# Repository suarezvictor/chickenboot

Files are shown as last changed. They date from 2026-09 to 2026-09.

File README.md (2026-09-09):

# ChickenBoot

The unbrickable and versatile embeddable boot loader  

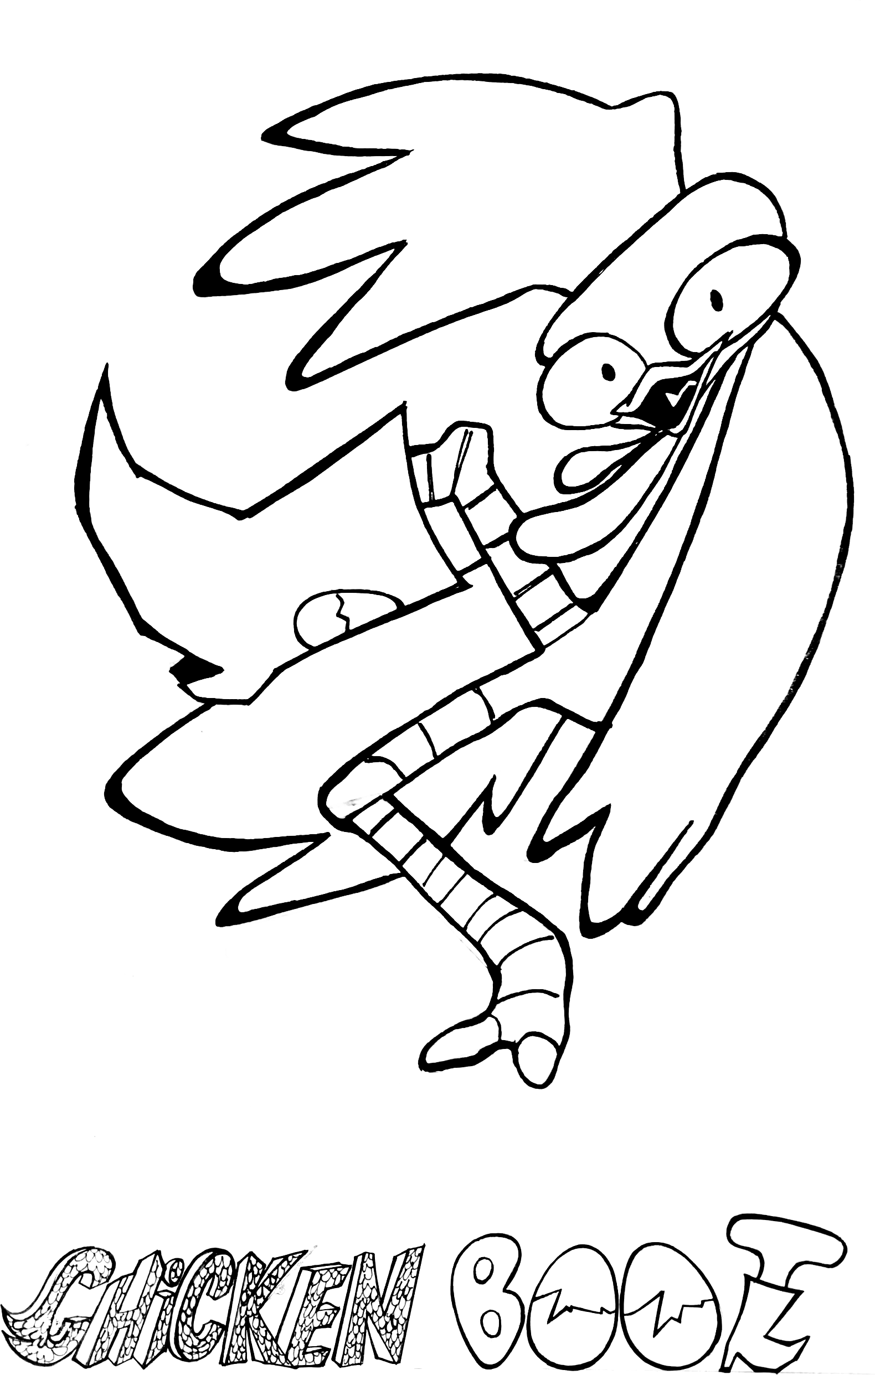
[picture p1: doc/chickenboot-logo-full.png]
  

# Building

To build the firmware:  
```
export PICO_SDK_PATH=$HOME/pico/pico-sdk

cd firmware
cmake -S . -B build -DPICO_BOARD=pico
make -C build -j
```

Then copy the build/main.uf2 file to the virtual drive (created by holding the BOOT button, the usual label for the drive is RPI-RP2)
# PCB design files

There are two board designs: one based on a MCU from WCH, the other based on a Raspberry Pi Pico.  

for details, read [Design document](DESIGN.md)

## View the boards online:  
The interactive viewer allows to explore the design in full without the need of installing any tools

- [RPI based design](https://kicanvas.org/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)

- [WCH based design](https://kicanvas.org/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)

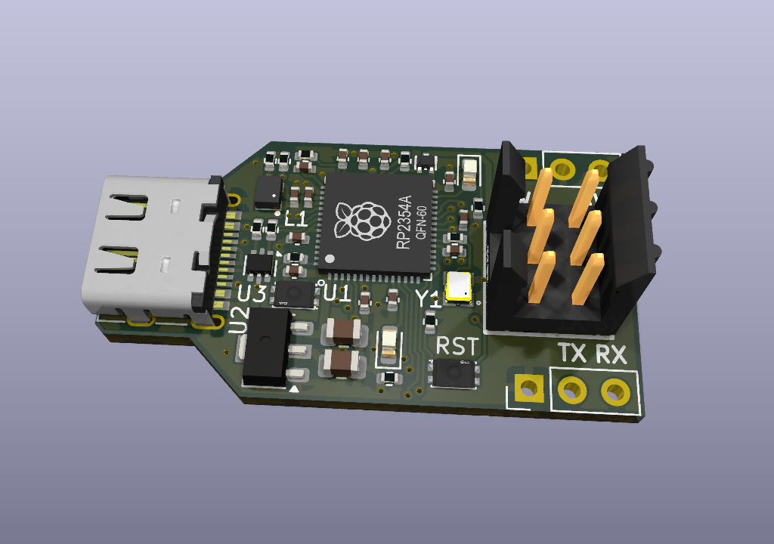
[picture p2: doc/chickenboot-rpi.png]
  
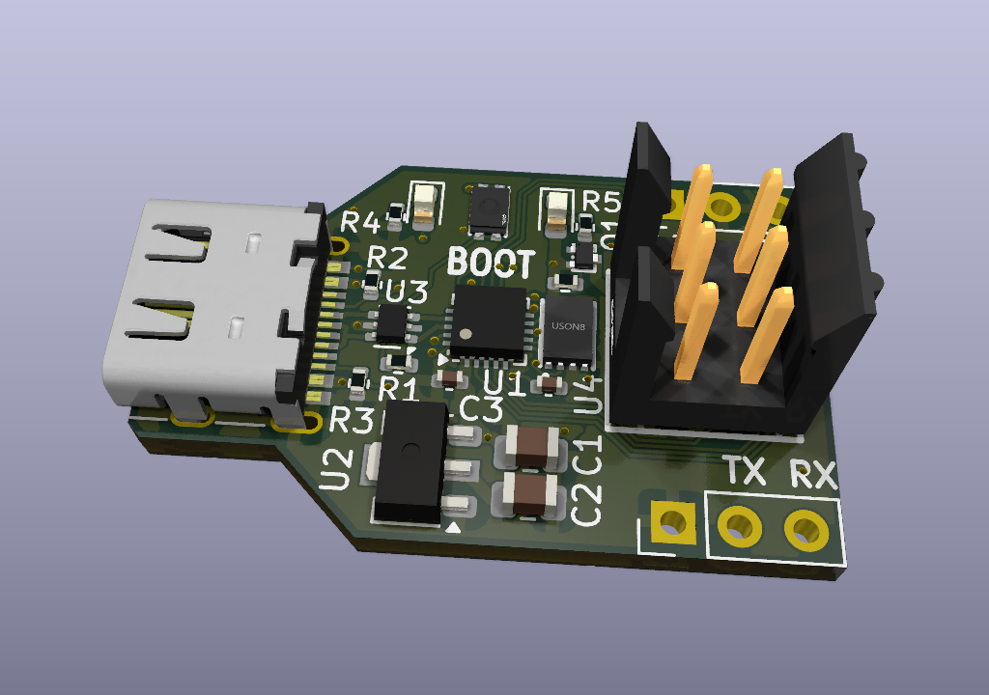
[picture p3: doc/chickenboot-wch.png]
  

# Licensing
Hardware design files are licensed under the [CERN-OHL-S-2.0](https://opensource.org/license/CERN-OHL-S-2.0) unless otherwise stated.  
Source code is licensed under the [AGPL-3.0](https://opensource.org/license/agpl-3-0) unless otherwise stated.  
  
# Funding
This project is supported by [The Open Source Firmware Foundation](https://www.osfw.foundation/)

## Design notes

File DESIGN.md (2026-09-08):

#Design criteria
## Objective
The current objective of the project aims to provide a practically negligible-cost, self-recovering, autonomous FPGA/MCU programming subsystem that can be embedded into embedded products.

# MCU selection

## Hard requirements
* Unbrickable: the MCU includes a bootloader in ROM
* No need of external adapters: the ROM bootloader suppoprts USB
* Small size: to prevent adding "real estate" requirements in PCB. Targew is 7x7mm max.
* Very low cost: if cost were high, it would justify an external programmer. Target is $2 max.

## Desirable features
* Large internal flash: So it can replace the flash required by FPGAs or complex SoC
* No radio: the radio of some MCUs adds a compliance burden for marketable designs.
* No BGA package: to simplify PCB and reduce cost

After evaluating those requirements, the *RP2354A* MCU appears to be a unicorn device, since the only capable of satisfying all of the above: 7x7mm package and 2 MB flash, at just $1.2.
Notable alternatives in a small package are ESP32 and Bouffalo Labs MCUs, being small, cheap and with considerable flash. but they have the radio issue, or Artery AT32F435CMU7, but about $3 and less mature ecosystem.
Others from WCH like CH32V203F8U6 and CH32X035F8U6 comes in 3x3mm package and at < $0.5 cost, but it lacks a large internal flash.

There is an issue regarding using just 2 MB of flash since some FPGAs expect up to 64MB for bistestream storage. But it is solvable by usign an external flash with a RP2040/RP2350 MCU, or by compression (tested bitstreams are about 4X compressible with lightweight algorithms like LZ4 which is truly fast for streaming decompression).

Note that the RP2350 has a internal 1.1V DC-DC requiring a 2x1.6mm inductor (not needed by the RP2040 LDO) but this can be skipped since the core voltage of the MCU matches the core voltage of FPGAs and the MCU is known for its flexibility of voltage and frequency of operation, so the same supply can be used saving PCB area.

# WCH board option

A board based on the CH32X035F8U6 MCU was also designed paired with an external ISSI IS25WP016D-JULE-TR 16mbit flash (2x3mm), considering a WINBOND W25Q16JVUXIQ alternative but more expensive.

Combined area usage gets effectively 6.5x3mm, and price stays below $1, but it is expected that the firmware for this platform will be more complex (TinyUSB support is not as good) and also slower: its 48Mhz clock is significantly slower than the 150Mhz (overclockable) RP2354 which has a full featured PIO. The CH32X035 provides a PIOC but with restrictions on pin usage (not possible in the 20 pin version) and DMA clobbers unintended I/O pins.

# Firmware
## Desirable features
* Device agnostic: it would add much complexity if each device needs its custom algorithm 
* Firmware simplicity: restricting the capability of this firmware to upload the bitstream (or program) just to RAM eliminates the unpredictable timings of flash access. Lack of flash programming is not an issue since the selected MCU will store the bitstream of firmware to be run, so the device doesn't need to fetch it from a local flash.
* Ease of use at production by non-technical users: UF2 uploader imposeses *no drivers or tools installation on the host (PC), since the programmer shows as a "thumb" driver where the programming file can be copied.

Considering this, the format to store the programming data was XSVF: most FPGA tools generate SVF (ASCII format), but this is convertible to XSVF (binary format) by tools like OpenOCD's svf2xsvf. The firmware on the MCU need only to convert the XSVF commands to JTAG signals, and since the XSVF is generated once at the host, this makes it device agnostic (the host knows the nuances of each device to be programmed). Note that SVF files generally lacks polling commands to check "busy" bits, but those are really needed for programming flash devices, SRAM target can use worst-case timings since they're really small (a few clocks). In any case, XSVF supports wait loops that can be exploited for programming more complex devices.

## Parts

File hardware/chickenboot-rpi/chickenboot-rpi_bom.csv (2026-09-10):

Comment | Designator | Footprint | LCSC Part Number | MPN | MFG
100n | C18,C16,C14,C11,C8,C15,C13,C12,C17 | 0402 | C100072 | CL05A104KA5NNNC | Samsung Electro-Mechanics
1k | R1,R6 | 0402 | C105637 | RC0402JR-071KL | YAGEO
69168-106HLF | CN1 | CONN-TH_6P-P2.54_69168-X06 | C5410110 | 69168-106HLF
3.3u | L1 | L_pol_2016 | C42411119 | AOTA-B201610S3R3-101-T
10uF 10V | C1,C2 | 0805 | C32635
27 | R5,R8,R7,R9 | 0402 | C25100 | 0402WGF270JTCE | UNI-ROYAL(Uniroyal Elec)
RP2350_60QFN | U1 | RP2350-QFN-60-1EP_7x7_P0.4mm_EP3.4x3.4mm_ThermalVias | C41378174 | RP2354A
4.7u 10V | C5,C6,C3,C4 | C_0402_1005Metric_small_pads | C368809 | CL05A475KP5NRNC | Samsung Electro-Mechanics
YELLOW | LED2 | LED_0603_1608Metric | C965798 | XL-1608SURC-04 | XINGLIGHT
5.1K 1% | R10,R11,R2,R4,R3 | 0402 | C105872 | RC0402FR-075K1L | YAGEO
HT7533-1 | U2 | SOT-89-3 | C14289 | HT7533-1 | Holtek Semicon
USB_C_Receptacle_USB2.0 | J1 | USB_C_Receptacle_G-Switch_GT-USB-7010ASV | C2988369 | GT-USB-7010ASV | G-Switch
SW_Push | SW1,SW2 | SW-SMD_4P-L2.5-W1.6-LS2.9_STI-055A12AX | C41398745 | GT-TC194A-H0055-L1
WPM2093-3/TR | Q2 | SOT-723_L1.2-W0.8-P0.80-LS1.2-BR | C2931332 | WPM2093-3/TR | WILLSEMI(Will Semicon)
RED | LED1 | LED_0603_1608Metric | C965799 | XL-1608SURC-06 | XINGLIGHT
12MHz | Y1 | OSC-SMD_4P-L2.0-W1.6-BL_8NE | C54307921 | YE12MUBCE2O
USBLC6-2P6 | U3 | SOT-666 | C15999 | USBLC6-2P6 | STMicroelectronics

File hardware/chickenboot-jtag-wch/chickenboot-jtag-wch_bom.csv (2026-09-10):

Comment | Designator | Footprint | LCSC Part Number | MPN | MFG
10uF 10V | C1,C2 | 0805 | C32635
YELLOW | LED1 | LED_0603_1608Metric | C965798 | XL-1608SURC-04 | XINGLIGHT
5.1K 1% | R3,R4,R2,R1,R6,R5 | 0402 | C105872 | RC0402FR-075K1L | YAGEO
IS25WP016D-JULE-TR | U4 | USON-8_L3.0-W2.0-P0.50-BL-EP_IS25LP080D | C2976734 | IS25WP016D-JULE-TR | ISSI(Integrated Silicon Solution)
USB_C_Receptacle_USB2.0 | J1 | USB_C_Receptacle_G-Switch_GT-USB-7010ASV | C2988369 | GT-USB-7010ASV | G-Switch
.1uF | C4,C3 | 0402 | C100072 | CL05A104KA5NNNC | Samsung Electro-Mechanics
USBLC6-2P6 | U3 | SOT-666 | C15999 | USBLC6-2P6 | STMicroelectronics
WPM2093-3/TR | Q1 | SOT-723_L1.2-W0.8-P0.80-LS1.2-BR | C2931332 | WPM2093-3/TR | WILLSEMI(Will Semicon)
69168-106HLF | CN1 | CONN-TH_6P-P2.54_69168-X06 | C5410110 | 69168-106HLF
HT7533-1 | U2 | SOT-89-3 | C14289 | HT7533-1 | Holtek Semicon
SW_Push | SW1 | SW-SMD_4P-L2.5-W1.6-LS2.9_STI-055A12AX | C41398745 | GT-TC194A-H0055-L1
RED | LED2 | LED_0603_1608Metric | C965799 | XL-1608SURC-06 | XINGLIGHT
CH32X035F8U6 | U1 | QFN-20-1EP_3x3mm_P0.4mm_EP1.65x1.65mm_ThermalVias | C42442062 | CH32X035F8U6 | WCH(Jiangsu Qin Heng)

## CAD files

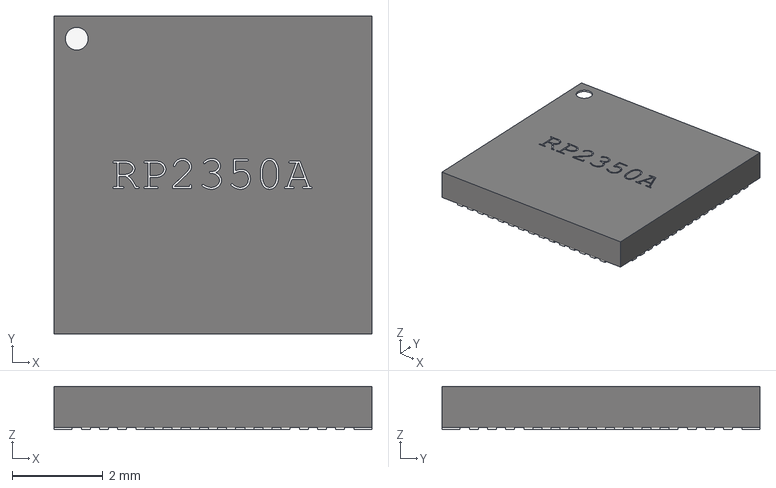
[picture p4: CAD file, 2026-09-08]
hardware/RP2350_QFN60.step
7.00 x 7.00 x 0.95 mm

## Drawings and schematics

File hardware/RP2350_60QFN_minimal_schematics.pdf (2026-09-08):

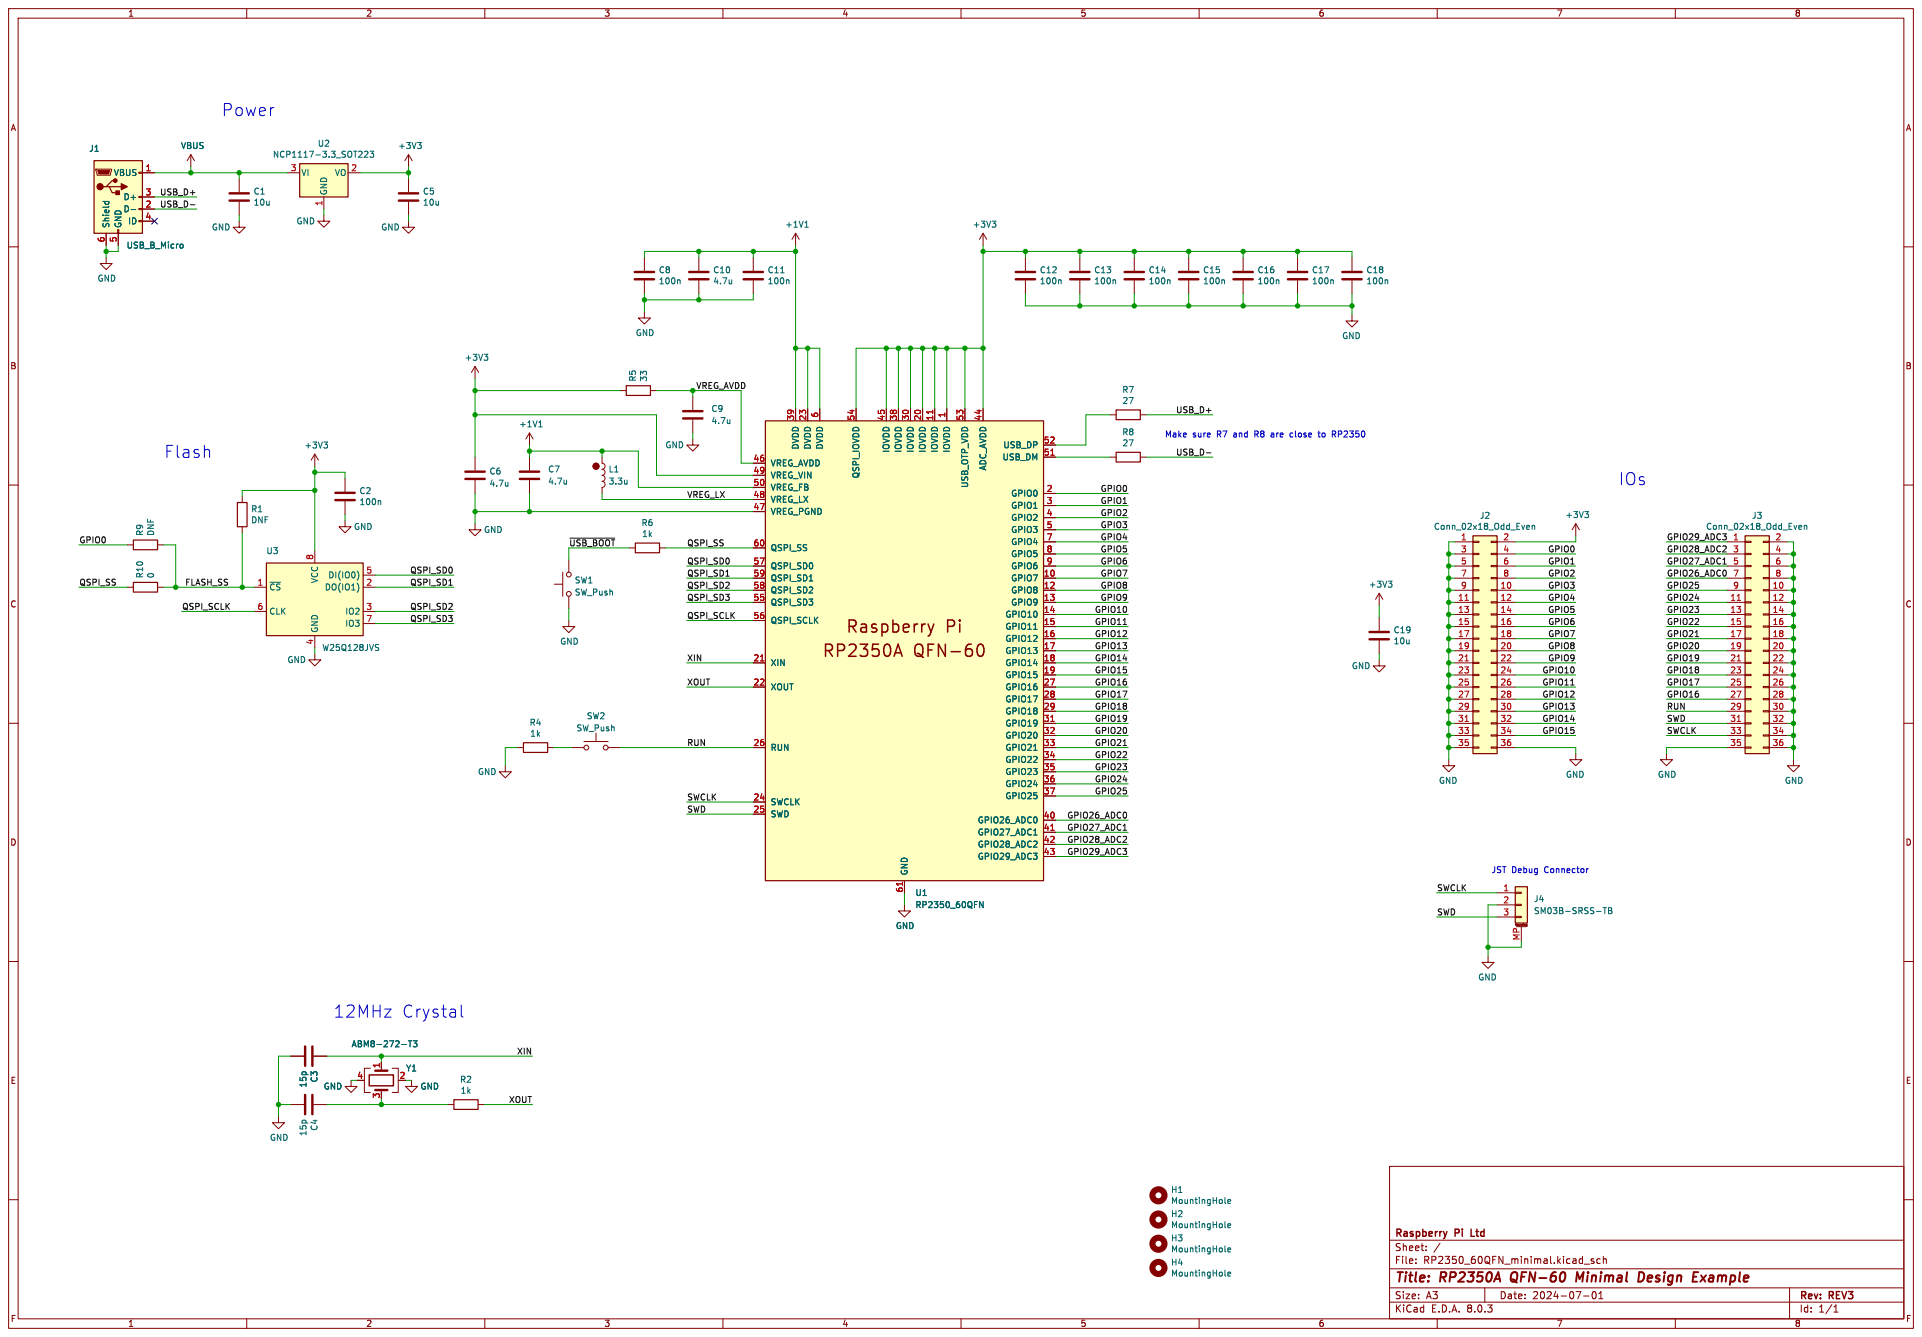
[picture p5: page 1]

J4SM03B-SRSS-TB GND GND

1 GPIO7 10 IOVDD 11 GPIO8 12 GPIO9 13 GPIO10 14 GPIO11 15 GPIO12 16 GPIO13 17 GPIO14 18 GPIO15 19 GPIO0 2 IOVDD 20 XIN 21 XOUT 22 DVDD 23 SWCLK 24 SWD 25 RUN 26 GPIO16 27 GPIO17 28 GPIO18 29 GPIO1 3 IOVDD 30 GPIO19 31 GPIO20 32 GPIO21 33 GPIO22 34 GPIO23 35 GPIO24 36 GPIO25 37 IOVDD 38 DVDD 39 GPIO2 4 GPIO26_ADC0 40 GPIO27_ADC1 41 GPIO28_ADC2 42 GPIO29_ADC3 43 ADC_AVDD 44 IOVDD 45 VREG_AVDD 46 VREG_PGND 47 VREG_LX 48 VREG_VIN 49 GPIO3 5 VREG_FB 50 USB_DM 51 USB_DP 52 USB_OTP_VDD 53 QSPI_IOVDD 54 QSPI_SD3 55 QSPI_SCLK 56 QSPI_SD0 57 QSPI_SD2 58 QSPI_SD1 59 DVDD
U1 RP2350_60QFN IOVDD

Make sure R7 and R8 are close to RP2350

H4 MountingHole H2 MountingHole H1 MountingHole H3 MountingHole

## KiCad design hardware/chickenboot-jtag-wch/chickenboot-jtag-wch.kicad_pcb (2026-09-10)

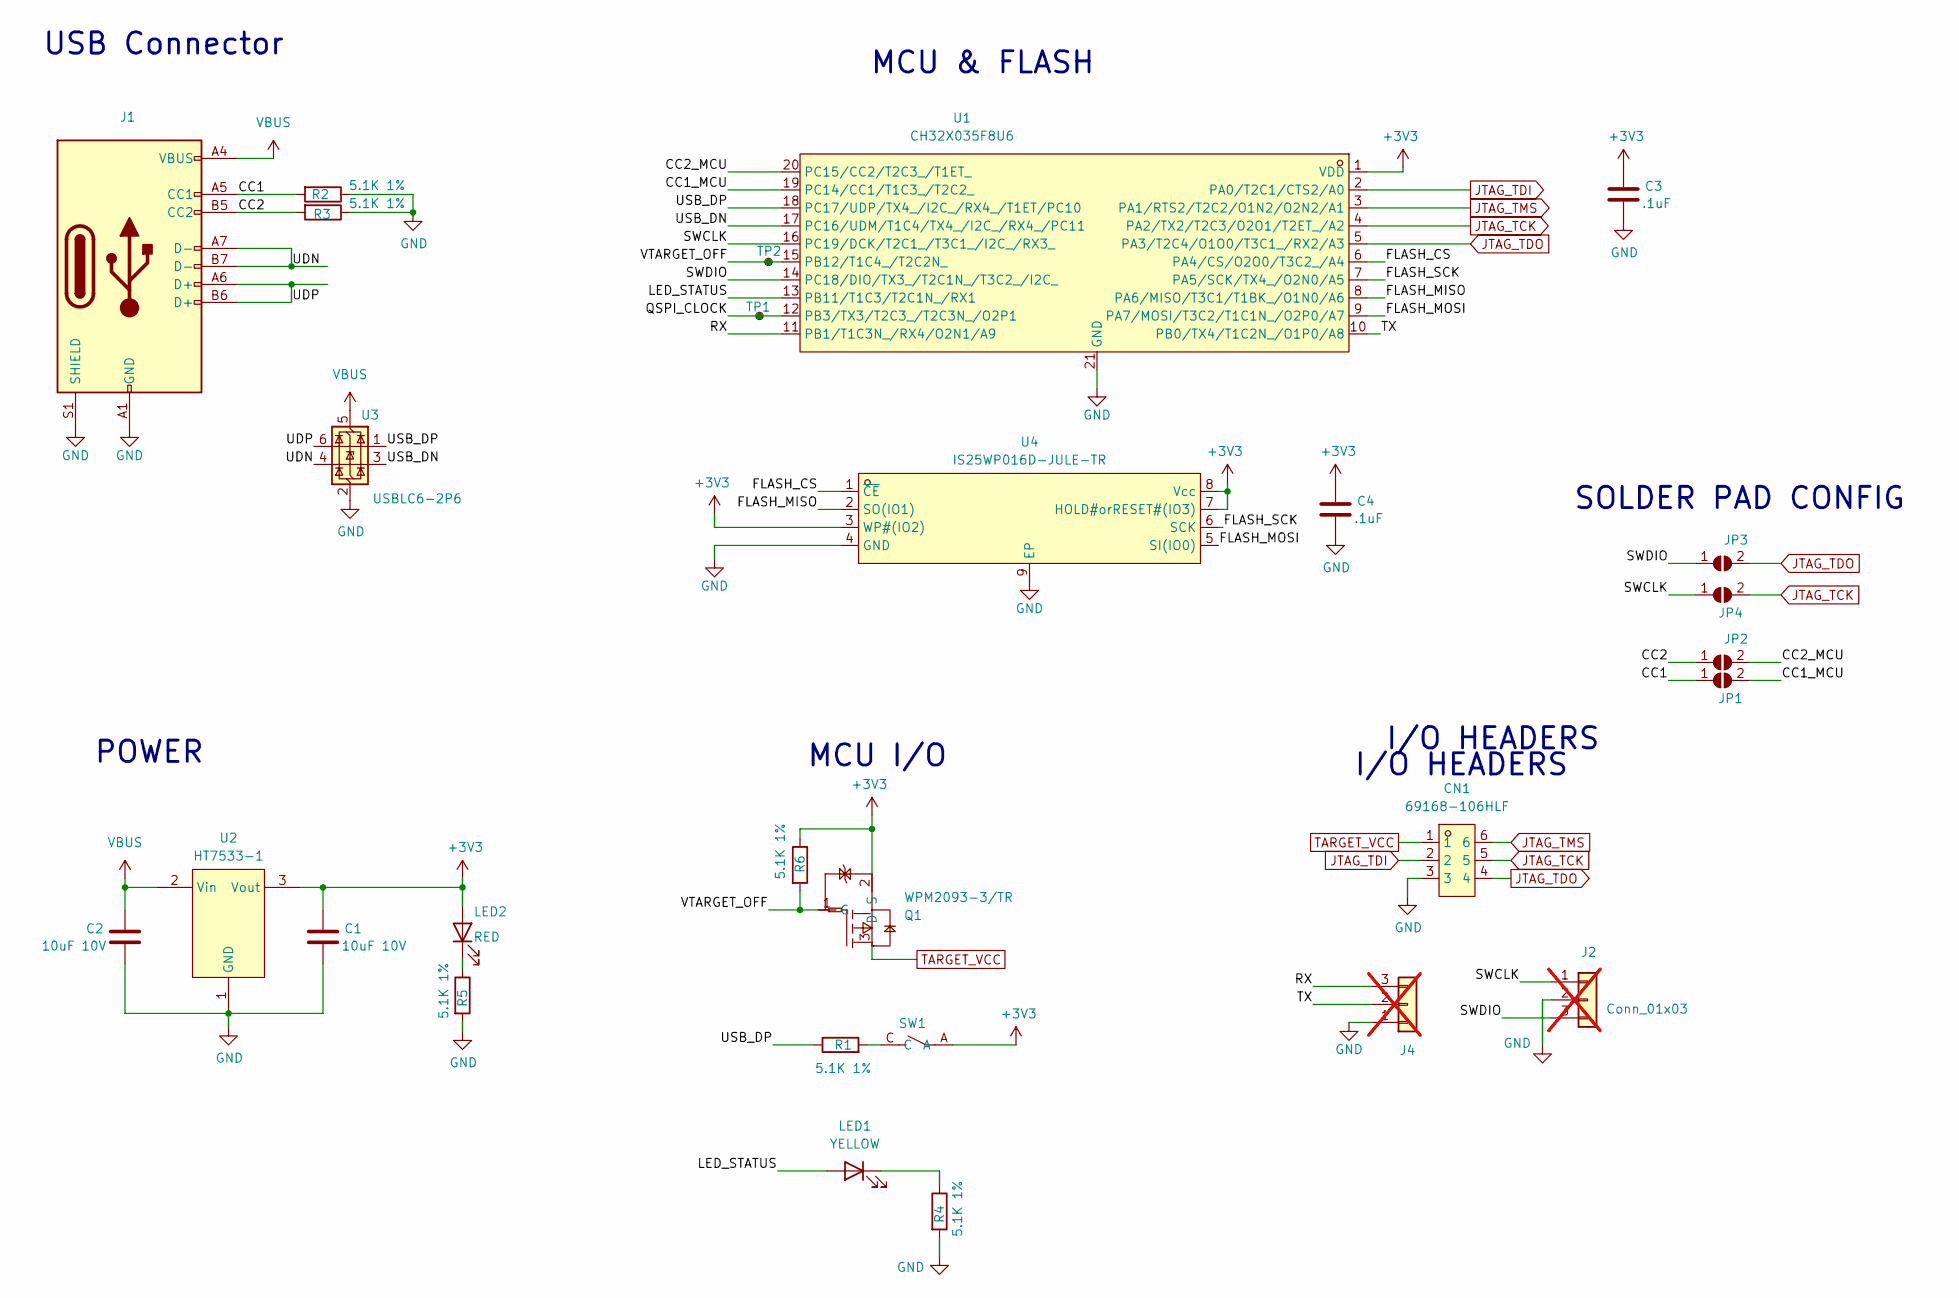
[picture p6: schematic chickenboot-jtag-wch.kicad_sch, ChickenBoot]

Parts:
C1, C2: 10uF 10V; C_0805_2012Metric; LCSC Part Number C32635
C3, C4: .1uF; C_0402_1005Metric
CN1: 69168-106HLF; CONN-TH_6P-P2.54_69168-X06; MPN 69168-106HLF; LCSC Part Number C5410110
J1: USB_C_Receptacle_USB2.0; USB_C_Receptacle_G-Switch_GT-USB-7010ASV; MPN GT-USB-7010ASV
J2, J4: Conn_01x03; PinHeader_1x03_P2.54mm_Vertical; not fitted
JP1, JP2, JP3, JP4: SolderJumper_2_Open; SolderJumper-2_P1.3mm_Open_RoundedPad1.0x1.5mm
LED1: YELLOW; LED_0603_1608Metric; MPN XL-1608SURC-04
LED2: RED; LED_0603_1608Metric; MPN XL-1608SURC-06
Q1: WPM2093-3/TR; SOT-723_L1.2-W0.8-P0.80-LS1.2-BR; MPN WPM2093-3/TR; LCSC Part C2931332
R1, R2, R3, R4, R5, R6: 5.1K 1%; R_0402_1005Metric
SW1: SW_Push; SW-SMD_4P-L2.5-W1.6-LS2.9_STI-055A12AX; MPN GT-TC194A-H0055-L1; LCSC Part Number C41398745
TP1, TP2: TestPoint_Small; TestPoint_Pad_1.5x1.5mm
U1: CH32X035F8U6; QFN-20-1EP_3x3mm_P0.4mm_EP1.65x1.65mm_ThermalVias; MPN CH32X035F8U6; LCSC Part Number C42442062
U2: HT7533-1; SOT-89-3; MPN HT7533-1; LCSC Part Number C14289
U3: USBLC6-2P6; SOT-666; MPN USBLC6-2P6; LCSC Part Number C15999
U4: IS25WP016D-JULE-TR; USON-8_L3.0-W2.0-P0.50-BL-EP_IS25LP080D; MPN IS25WP016D-JULE-TR; LCSC Part C2976734

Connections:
+3V3: C1.1, C3.1, C4.1, LED2.2 (A), Q1.2 (S), R6.1, SW1.A, U1.1 (VDD), U2.3 (Vout), U4.3 (WP#(IO2)), U4.7 (HOLD#orRESET#(IO3)), U4.8 (Vcc)
/CC1: J1.A5 (CC1), JP1.1 (A), R2.2
/CC1_MCU: JP1.2 (B), U1.19 (PC14/CC1/T1C3_/T2C2_)
/CC2: J1.B5 (CC2), JP2.1 (A), R3.2
/CC2_MCU: JP2.2 (B), U1.20 (PC15/CC2/T2C3_/T1ET_)
/FLASH_CS: U1.6 (PA4/CS/O2O0/T3C2_/A4), U4.1 (~CE)
/FLASH_MISO: U1.8 (PA6/MISO/T3C1/T1BK_/O1N0/A6), U4.2 (SO(IO1))
/FLASH_MOSI: U1.9 (PA7/MOSI/T3C2/T1C1N_/O2P0/A7), U4.5 (SI(IO0))
/FLASH_SCK: U1.7 (PA5/SCK/TX4_/O2N0/A5), U4.6 (SCK)
/LED_STATUS: LED1.2 (A), U1.13 (PB11/T1C3/T2C1N_/RX1)
/QSPI_CLOCK: TP1.1, U1.12 (PB3/TX3/T2C3_/T2C3N_/O2P1)
/RX: J4.3, U1.11 (PB1/T1C3N_/RX4/O2N1/A9)
/SWCLK: J2.1, JP4.1 (A), U1.16 (PC19/DCK/T2C1_/T3C1_/I2C_/RX3_)
/SWDIO: J2.3, JP3.1 (A), U1.14 (PC18/DIO/TX3_/T2C1N_/T3C2_/I2C_)
/TX: J4.2, U1.10 (PB0/TX4/T1C2N_/O1P0/A8)
/UDN: J1.A7 (D-), J1.B7 (D-), U3.4 (I/O2)
/UDP: J1.A6 (D+), J1.B6 (D+), U3.6 (I/O1)
/USB_DN: U1.17 (PC16/UDM/T1C4/TX4_/I2C_/RX4_/PC11), U3.3 (I/O2)
/USB_DP: R1.1, U1.18 (PC17/UDP/TX4_/I2C_/RX4_/T1ET/PC10), U3.1 (I/O1)
/VTARGET_OFF: Q1.1 (G), R6.2, TP2.1, U1.15 (PB12/T1C4_/T2C2N_)
GND: C1.2, C2.2, C3.2, C4.2, CN1.3, J1.A1 (GND), J1.A12 (GND), J1.B1 (GND), J1.B12 (GND), J1.S1 (SHIELD), J2.2, J4.1, R2.1, R3.1, R4.2, R5.2, U1.21 (GND), U2.1 (GND), U3.2 (GND), U4.4 (GND), U4.9 (EP)
JTAG_TCK: CN1.5, JP4.2 (B), U1.4 (PA2/TX2/T2C3/O2O1/T2ET_/A2)
JTAG_TDI: CN1.2, U1.2 (PA0/T2C1/CTS2/A0)
JTAG_TDO: CN1.4, JP3.2 (B), U1.5 (PA3/T2C4/O1O0/T3C1_/RX2/A3)
JTAG_TMS: CN1.6, U1.3 (PA1/RTS2/T2C2/O1N2/O2N2/A1)
unnamed: LED1.1 (K), R4.1
unnamed: LED2.1 (K), R5.1
unnamed: R1.2, SW1.C
TARGET_VCC: CN1.1, Q1.3 (D)
VBUS: C2.1, J1.A4 (VBUS), J1.A9 (VBUS), J1.B4 (VBUS), J1.B9 (VBUS), U2.2 (Vin), U3.5 (VBUS)

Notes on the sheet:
MCU & FLASH
SOLDER PAD CONFIG
MCU I/O
I/O HEADERS
POWER
USB Connector

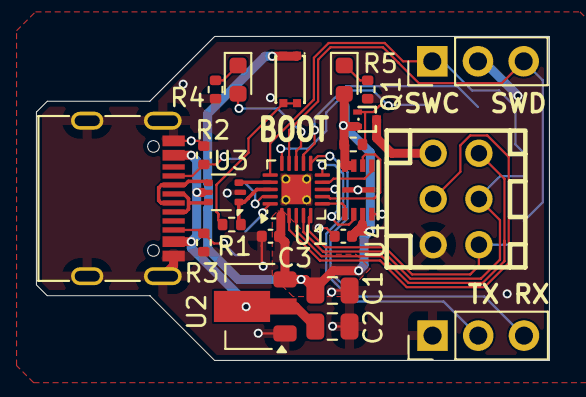
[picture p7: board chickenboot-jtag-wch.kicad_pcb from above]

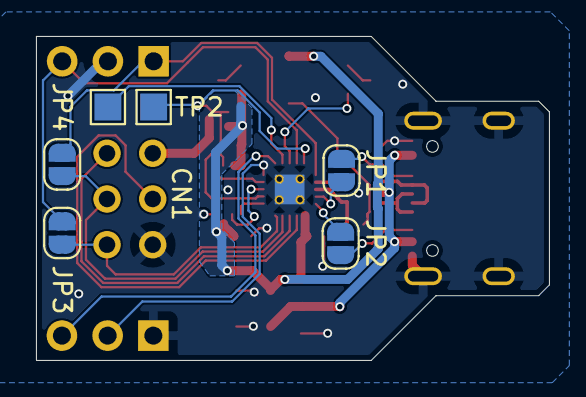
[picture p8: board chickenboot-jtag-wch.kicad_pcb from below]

Board: 2 copper layers, 28.5 x 18.0 mm, 28 parts (6 on the bottom side), 30 nets.

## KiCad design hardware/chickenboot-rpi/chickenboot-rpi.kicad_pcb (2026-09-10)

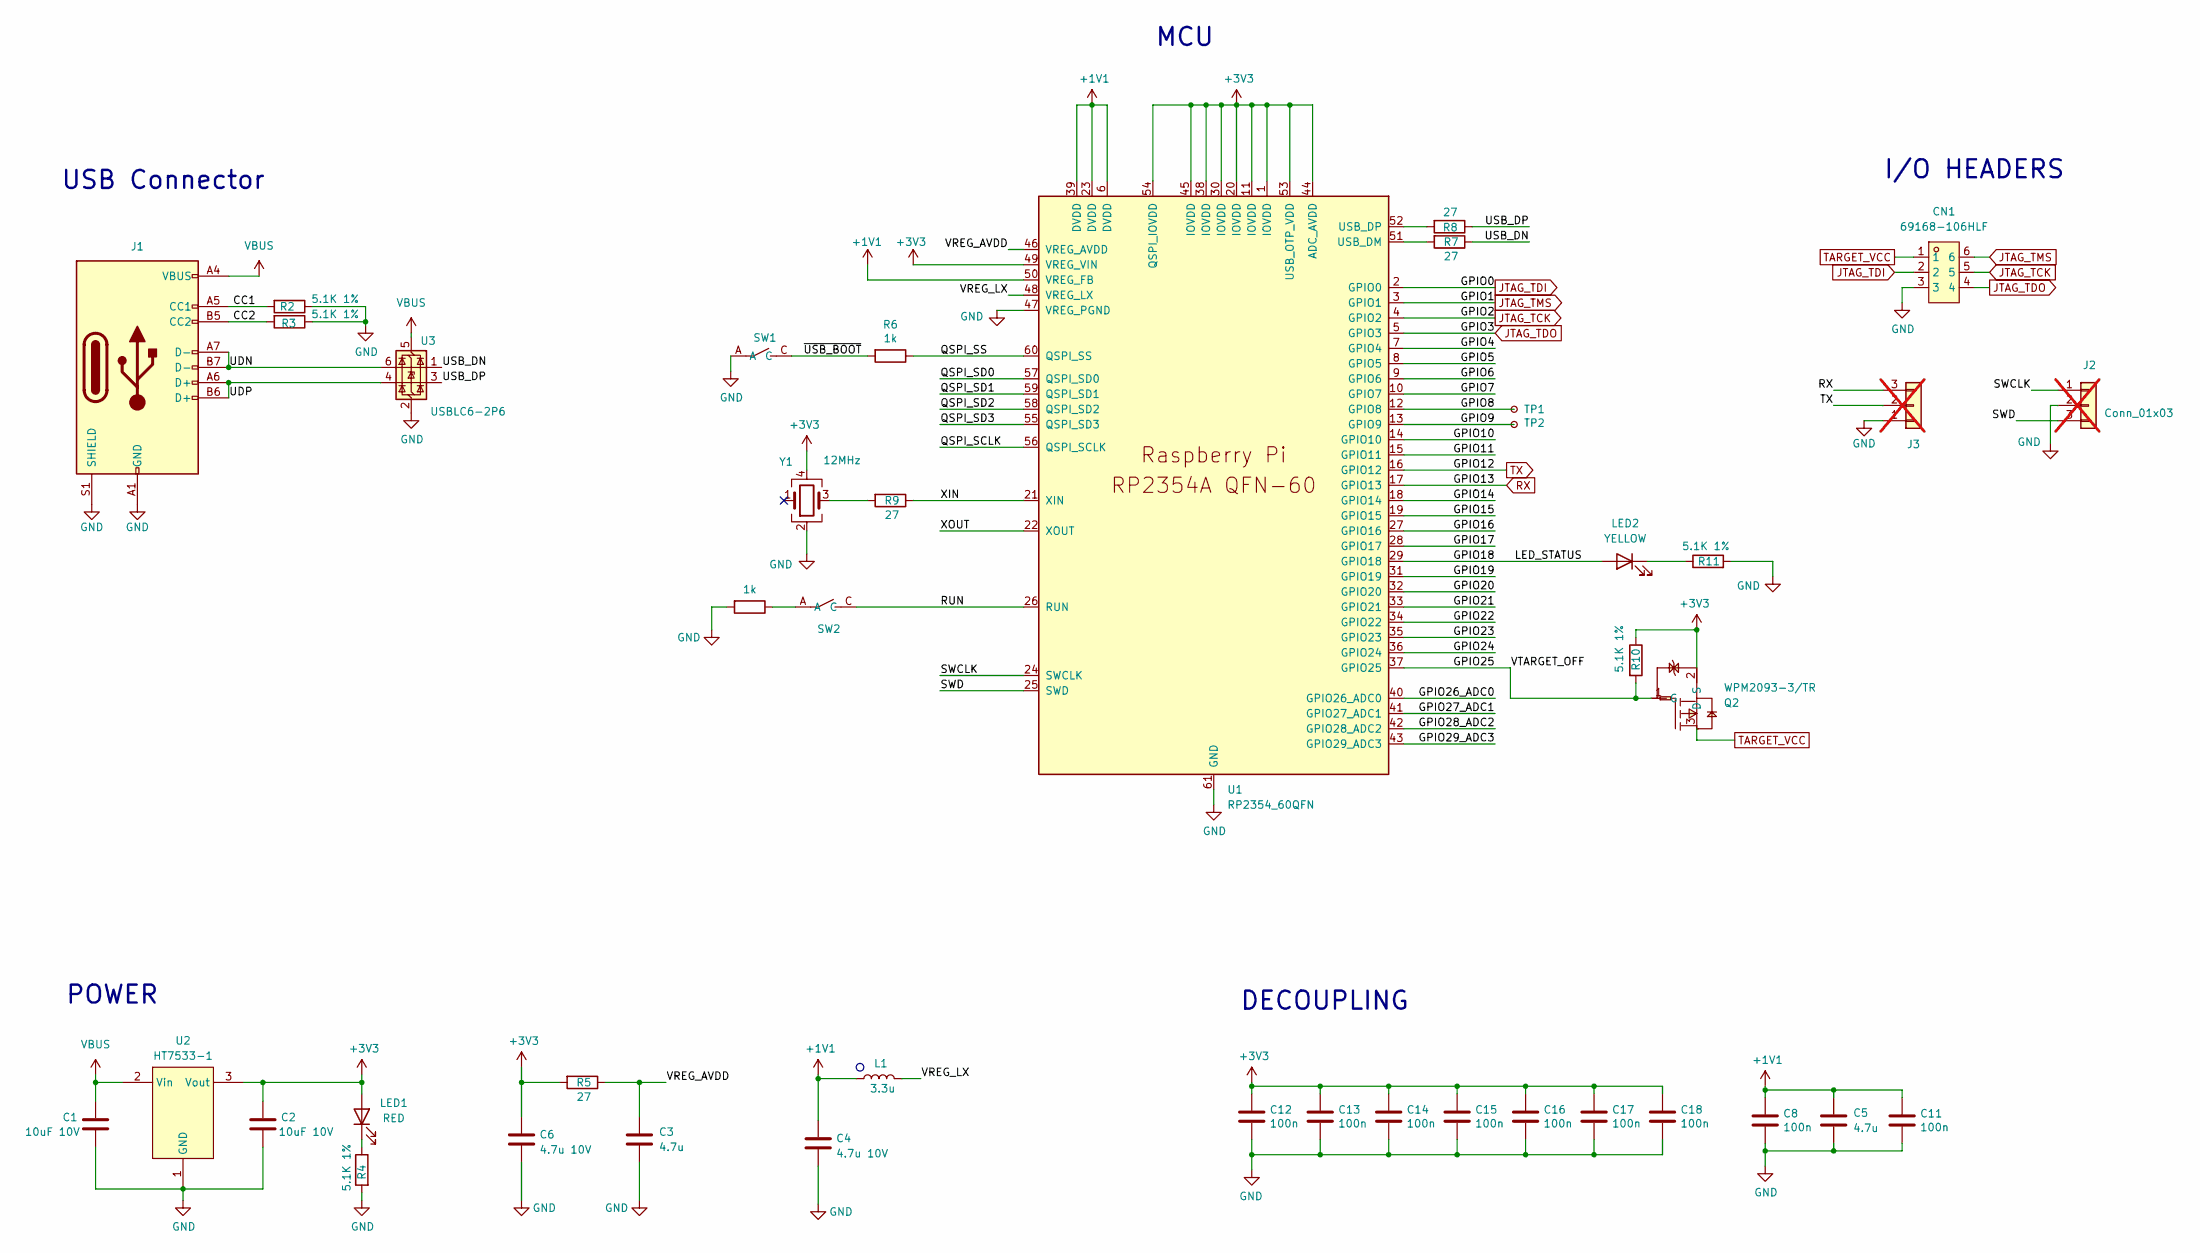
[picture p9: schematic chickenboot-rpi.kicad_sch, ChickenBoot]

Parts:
C1, C2: 10uF 10V; C_0805_2012Metric; LCSC Part Number C32635
C3, C5: 4.7u; C_0402_1005Metric_small_pads; MPN CL05A475KP5NRNC
C4, C6: 4.7u 10V; C_0402_1005Metric_small_pads; MPN CL05A475KP5NRNC
C8, C11, C12, C13, C14, C15, C16, C17, C18: 100n; C_0402_1005Metric
CN1: 69168-106HLF; CONN-TH_6P-P2.54_69168-X06; MPN 69168-106HLF; LCSC Part Number C5410110
J1: USB_C_Receptacle_USB2.0; USB_C_Receptacle_G-Switch_GT-USB-7010ASV; MPN GT-USB-7010ASV
J2, J3: Conn_01x03; PinHeader_1x03_P2.54mm_Vertical; not fitted
L1: 3.3u; L_pol_2016; MPN AOTA-B201610S3R3-101-T; LCSC Part Number C42411119
LED1: RED; LED_0603_1608Metric; MPN XL-1608SURC-06
LED2: YELLOW; LED_0603_1608Metric; MPN XL-1608SURC-04
Q2: WPM2093-3/TR; SOT-723_L1.2-W0.8-P0.80-LS1.2-BR; MPN WPM2093-3/TR; LCSC Part C2931332
R1, R6: 1k; R_0402_1005Metric
R2, R3, R4, R10, R11: 5.1K 1%; R_0402_1005Metric
R5, R7, R8, R9: 27; R_0402_1005Metric
SW1, SW2: SW_Push; SW-SMD_4P-L2.5-W1.6-LS2.9_STI-055A12AX; MPN GT-TC194A-H0055-L1; LCSC Part Number C41398745
TP1, TP2: TestPoint_Small; TestPoint_Pad_1.5x1.5mm
U1: RP2354_60QFN; RP2350-QFN-60-1EP_7x7_P0.4mm_EP3.4x3.4mm_ThermalVias; MPN RP2354A; LCSC Part Number C41378174
U2: HT7533-1; SOT-89-3; MPN HT7533-1; LCSC Part Number C14289
U3: USBLC6-2P6; SOT-666; MPN USBLC6-2P6; LCSC Part Number C15999
Y1: 12MHz; OSC-SMD_4P-L2.0-W1.6-BL_8NE; MPN YE12MUBCE2O; LCSC Part Number C54307921

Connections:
+1V1: C4.1, C5.1, C8.1, C11.1, L1.1, U1.6 (DVDD), U1.23 (DVDD), U1.39 (DVDD), U1.50 (VREG_FB)
+3V3: C2.1, C6.1, C12.1, C13.1, C14.1, C15.1, C16.1, C17.1, C18.1, LED1.2 (A), Q2.2 (S), R5.2, R10.1, U1.1 (IOVDD), U1.11 (IOVDD), U1.20 (IOVDD), U1.30 (IOVDD), U1.38 (IOVDD), U1.44 (ADC_AVDD), U1.45 (IOVDD), U1.49 (VREG_VIN), U1.53 (USB_OTP_VDD), U1.54 (QSPI_IOVDD), U2.3 (Vout), Y1.4
/CC1: J1.A5 (CC1), R2.2
/CC2: J1.B5 (CC2), R3.2
/GPIO4: U1.7 (GPIO4)
/GPIO5: U1.8 (GPIO5)
/GPIO6: U1.9 (GPIO6)
/GPIO7: U1.10 (GPIO7)
/GPIO8: TP1.1, U1.12 (GPIO8)
/GPIO9: TP2.1, U1.13 (GPIO9)
/GPIO10: U1.14 (GPIO10)
/GPIO11: U1.15 (GPIO11)
/GPIO14: U1.18 (GPIO14)
/GPIO15: U1.19 (GPIO15)
/GPIO16: U1.27 (GPIO16)
/GPIO17: U1.28 (GPIO17)
/GPIO18: LED2.2 (A), U1.29 (GPIO18)
/GPIO19: U1.31 (GPIO19)
/GPIO20: U1.32 (GPIO20)
/GPIO21: U1.33 (GPIO21)
/GPIO22: U1.34 (GPIO22)
/GPIO23: U1.35 (GPIO23)
/GPIO24: U1.36 (GPIO24)
/GPIO25: Q2.1 (G), R10.2, U1.37 (GPIO25)
/GPIO26_ADC0: U1.40 (GPIO26_ADC0)
/GPIO27_ADC1: U1.41 (GPIO27_ADC1)
/GPIO28_ADC2: U1.42 (GPIO28_ADC2)
/GPIO29_ADC3: U1.43 (GPIO29_ADC3)
/QSPI_SCLK: U1.56 (QSPI_SCLK)
/QSPI_SD0: U1.57 (QSPI_SD0)
/QSPI_SD1: U1.59 (QSPI_SD1)
/QSPI_SD2: U1.58 (QSPI_SD2)
/QSPI_SD3: U1.55 (QSPI_SD3)
/QSPI_SS: R6.1, U1.60 (QSPI_SS)
/RUN: SW2.C, U1.26 (RUN)
/SWCLK: J2.1, U1.24 (SWCLK)
/SWD: J2.3, U1.25 (SWD)
/UDN: J1.A7 (D-), J1.B7 (D-), U3.6 (I/O1)
/UDP: J1.A6 (D+), J1.B6 (D+), U3.4 (I/O2)
/USB_DN: R7.1, U3.1 (I/O1)
/USB_DP: R8.1, U3.3 (I/O2)
/VREG_AVDD: C3.1, R5.1, U1.46 (VREG_AVDD)
/VREG_LX: L1.2, U1.48 (VREG_LX)
/XIN: R9.1, U1.21 (XIN)
/XOUT: U1.22 (XOUT)
/~USB_BOOT: R6.2, SW1.C
GND: C1.2, C2.2, C3.2, C4.2, C5.2, C6.2, C8.2, C11.2, C12.2, C13.2, C14.2, C15.2, C16.2, C17.2, C18.2, CN1.3, J1.A1 (GND), J1.A12 (GND), J1.B1 (GND), J1.B12 (GND), J1.S1 (SHIELD), J2.2, J3.1, R1.2, R2.1, R3.1, R4.2, R11.2, SW1.A, U1.47 (VREG_PGND), U1.61 (GND), U2.1 (GND), U3.2 (GND), Y1.2
JTAG_TCK: CN1.5, U1.4 (GPIO2)
JTAG_TDI: CN1.2, U1.2 (GPIO0)
JTAG_TDO: CN1.4, U1.5 (GPIO3)
JTAG_TMS: CN1.6, U1.3 (GPIO1)
unnamed: LED1.1 (K), R4.1
unnamed: LED2.1 (K), R11.1
unnamed: R1.1, SW2.A
unnamed: R9.2, Y1.3
unnamed: R7.2, U1.51 (USB_DM)
unnamed: R8.2, U1.52 (USB_DP)
RX: J3.3, U1.17 (GPIO13)
TARGET_VCC: CN1.1, Q2.3 (D)
TX: J3.2, U1.16 (GPIO12)
VBUS: C1.1, J1.A4 (VBUS), J1.A9 (VBUS), J1.B4 (VBUS), J1.B9 (VBUS), U2.2 (Vin), U3.5 (VBUS)

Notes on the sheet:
USB Connector
POWER
MCU
DECOUPLING
I/O HEADERS

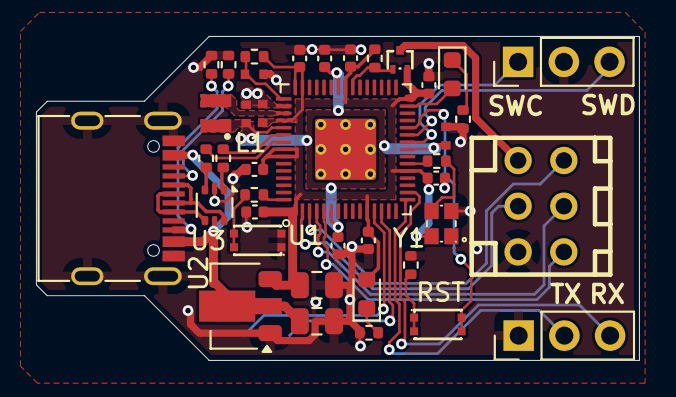
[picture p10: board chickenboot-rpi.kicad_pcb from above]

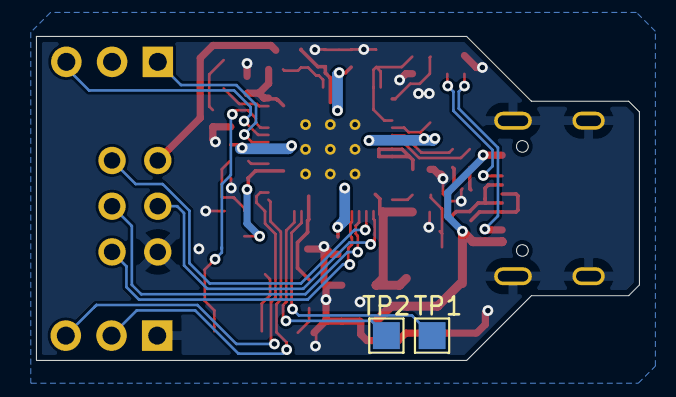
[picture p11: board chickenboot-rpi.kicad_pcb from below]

Board: 2 copper layers, 33.5 x 18.0 mm, 42 parts (2 on the bottom side), 35 nets.

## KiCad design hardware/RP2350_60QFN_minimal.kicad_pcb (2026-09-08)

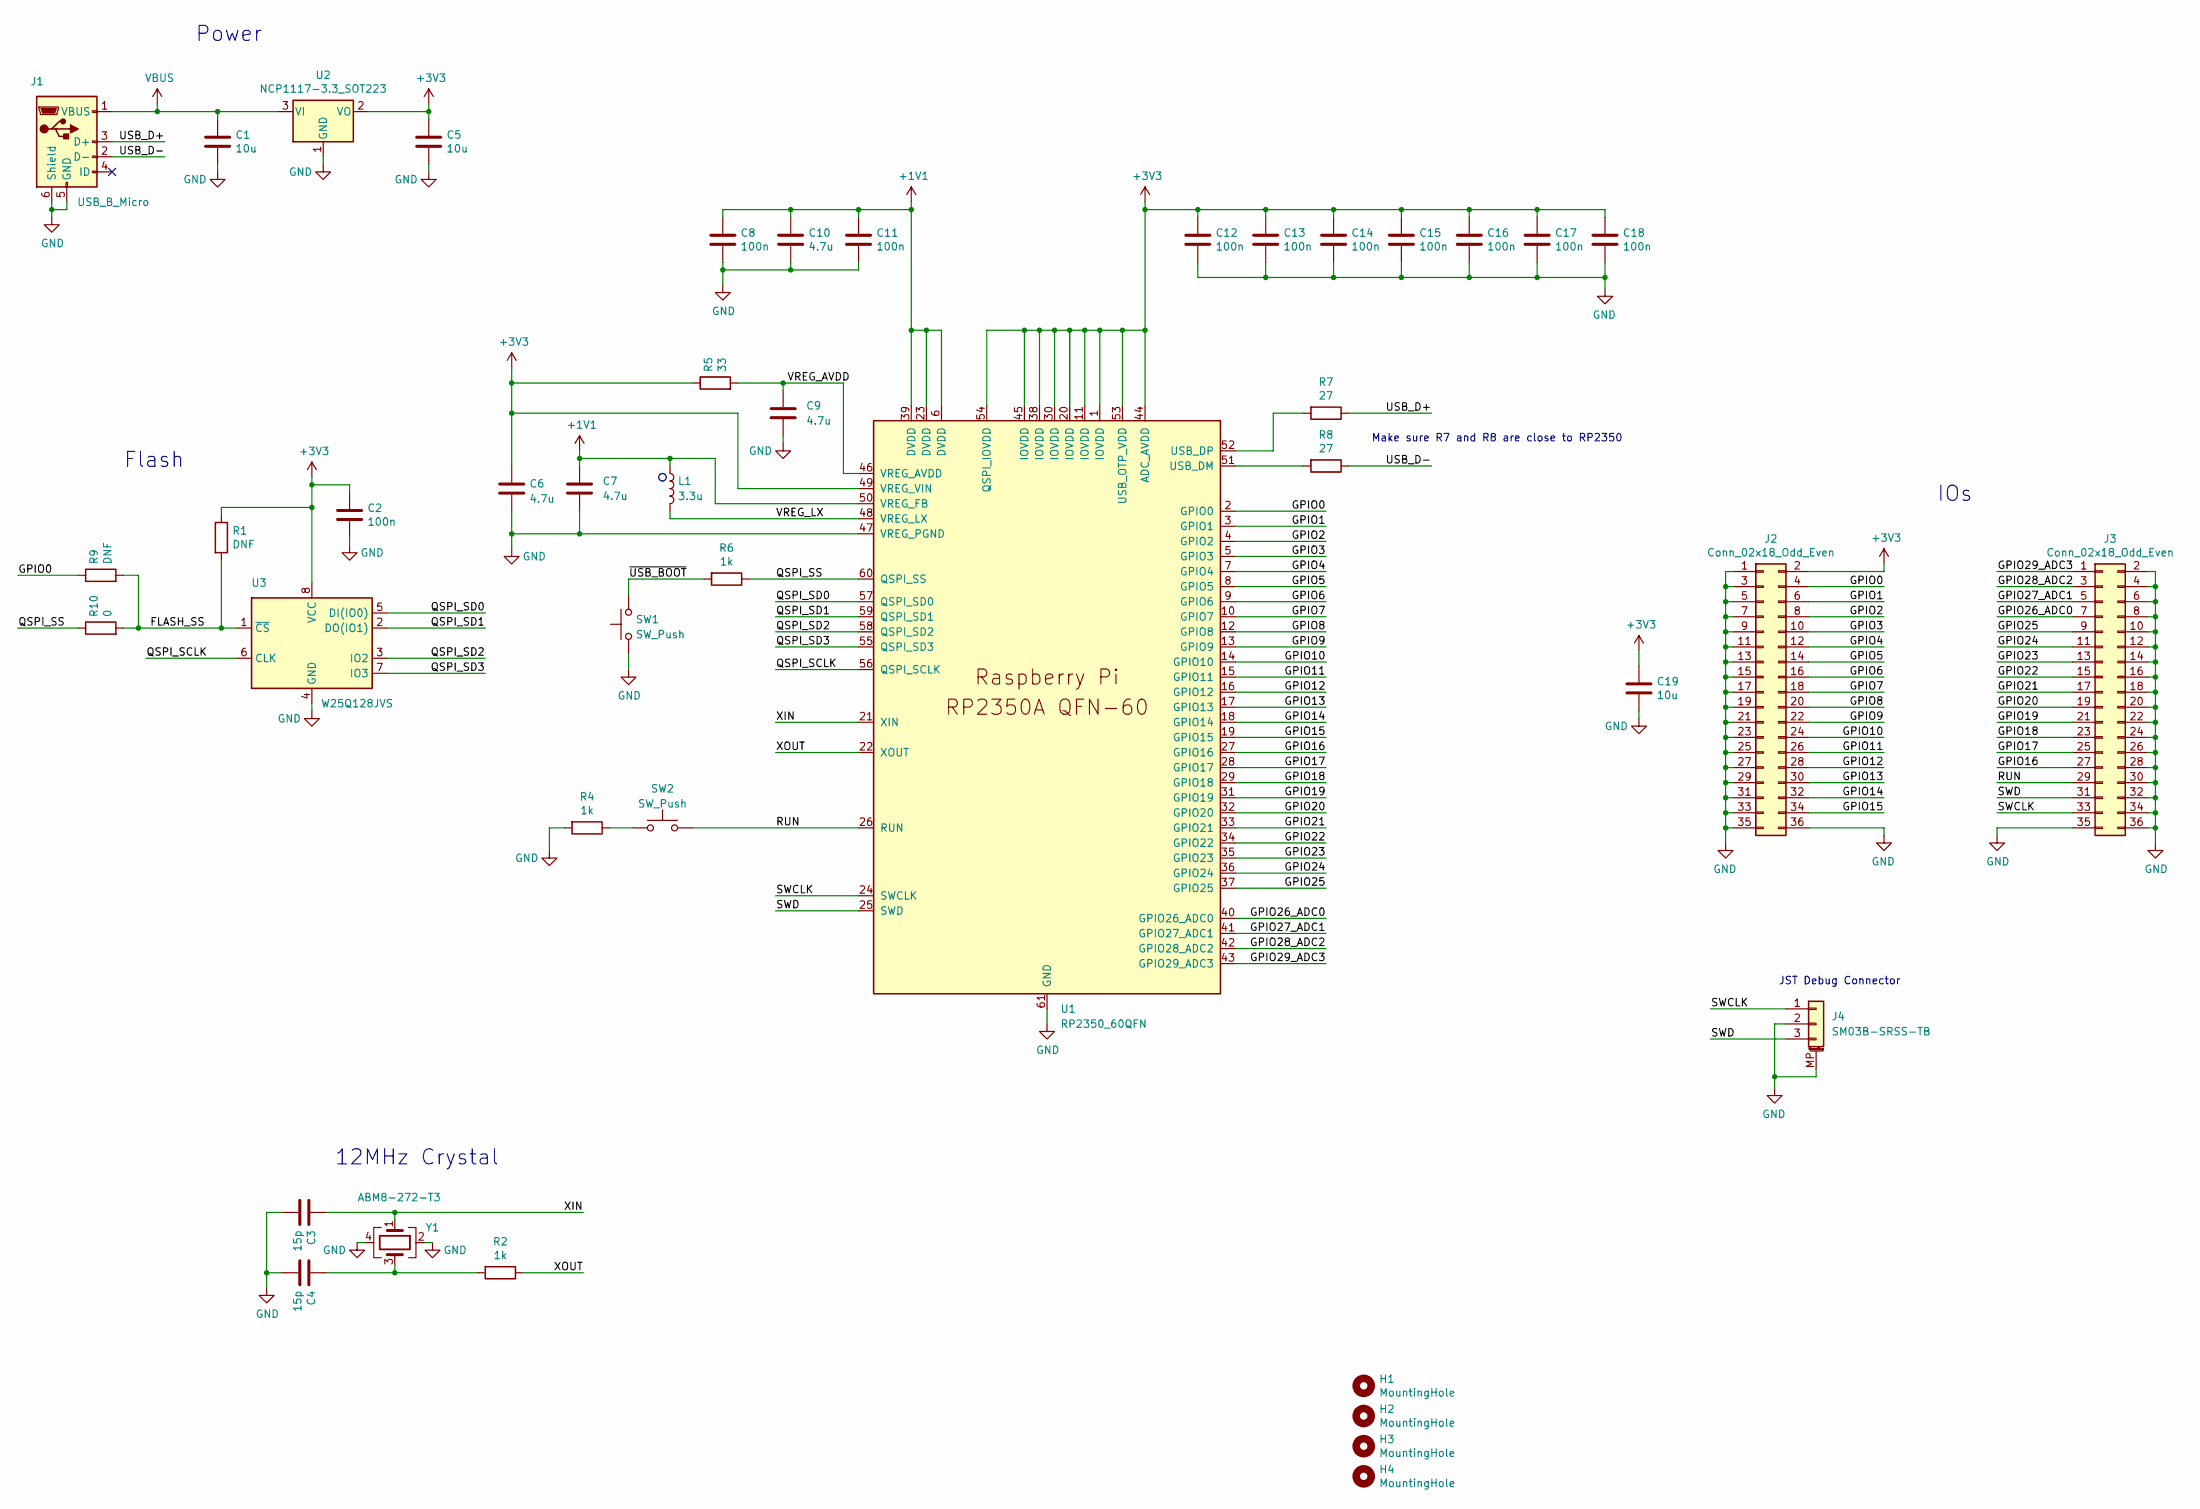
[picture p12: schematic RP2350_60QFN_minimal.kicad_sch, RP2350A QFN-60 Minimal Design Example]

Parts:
C1, C5, C19: 10u; C_0805_2012Metric
C2, C8, C11, C12, C13, C14, C15, C16, C17, C18: 100n; C_0402_1005Metric
C3, C4: 15p; C_0402_1005Metric
C6, C7: 4.7u; C_0402_1005Metric_small_pads
C9, C10: 4.7u; C_0402_1005Metric
H1, H2, H3, H4: MountingHole; MountingHole_2.7mm_M2.5
J1: USB_B_Micro; USB_Micro-B_Amphenol_10103594-0001LF_Horizontal
J2, J3: Conn_02x18_Odd_Even; PinHeader_2x18_P2.54mm_Vertical
J4: SM03B-SRSS-TB; JST_SH_SM03B-SRSS-TB_1x03-1MP_P1.00mm_Horizontal
L1: 3.3u; L_pol_2016
R1, R9: DNF; R_0402_1005Metric
R2, R4, R6: 1k; R_0402_1005Metric
R5: 33; R_0402_1005Metric
R7, R8: 27; R_0402_1005Metric
R10: 0; R_0402_1005Metric
SW1, SW2: SW_Push; SW_Push_1P1T_NO_Vertical_Wuerth_434133025816
U1: RP2350_60QFN; RP2350-QFN-60-1EP_7x7_P0.4mm_EP3.4x3.4mm_ThermalVias
U2: NCP1117-3.3_SOT223; SOT-223-3_TabPin2
U3: W25Q128JVS; SOIC-8_5.23x5.23mm_P1.27mm
Y1: ABM8-272-T3; Crystal_SMD_3225-4Pin_3.2x2.5mm

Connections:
+1V1: C7.1, C8.1, C10.1, C11.1, L1.1, U1.6 (DVDD), U1.23 (DVDD), U1.39 (DVDD), U1.50 (VREG_FB)
+3V3: C2.1, C5.1, C6.1, C12.1, C13.1, C14.1, C15.1, C16.1, C17.1, C18.1, C19.1, J2.2, R1.1, R5.1, U1.1 (IOVDD), U1.11 (IOVDD), U1.20 (IOVDD), U1.30 (IOVDD), U1.38 (IOVDD), U1.44 (ADC_AVDD), U1.45 (IOVDD), U1.49 (VREG_VIN), U1.53 (USB_OTP_VDD), U1.54 (QSPI_IOVDD), U2.2 (VO), U3.8 (VCC)
/FLASH_SS: R1.2, R9.2, R10.2, U3.1 (~CS)
/GPIO0: J2.4, R9.1, U1.2 (GPIO0)
/GPIO1: J2.6, U1.3 (GPIO1)
/GPIO2: J2.8, U1.4 (GPIO2)
/GPIO3: J2.10, U1.5 (GPIO3)
/GPIO4: J2.12, U1.7 (GPIO4)
/GPIO5: J2.14, U1.8 (GPIO5)
/GPIO6: J2.16, U1.9 (GPIO6)
/GPIO7: J2.18, U1.10 (GPIO7)
/GPIO8: J2.20, U1.12 (GPIO8)
/GPIO9: J2.22, U1.13 (GPIO9)
/GPIO10: J2.24, U1.14 (GPIO10)
/GPIO11: J2.26, U1.15 (GPIO11)
/GPIO12: J2.28, U1.16 (GPIO12)
/GPIO13: J2.30, U1.17 (GPIO13)
/GPIO14: J2.32, U1.18 (GPIO14)
/GPIO15: J2.34, U1.19 (GPIO15)
/GPIO16: J3.27, U1.27 (GPIO16)
/GPIO17: J3.25, U1.28 (GPIO17)
/GPIO18: J3.23, U1.29 (GPIO18)
/GPIO19: J3.21, U1.31 (GPIO19)
/GPIO20: J3.19, U1.32 (GPIO20)
/GPIO21: J3.17, U1.33 (GPIO21)
/GPIO22: J3.15, U1.34 (GPIO22)
/GPIO23: J3.13, U1.35 (GPIO23)
/GPIO24: J3.11, U1.36 (GPIO24)
/GPIO25: J3.9, U1.37 (GPIO25)
/GPIO26_ADC0: J3.7, U1.40 (GPIO26_ADC0)
/GPIO27_ADC1: J3.5, U1.41 (GPIO27_ADC1)
/GPIO28_ADC2: J3.3, U1.42 (GPIO28_ADC2)
/GPIO29_ADC3: J3.1, U1.43 (GPIO29_ADC3)
/QSPI_SCLK: U1.56 (QSPI_SCLK), U3.6 (CLK)
/QSPI_SD0: U1.57 (QSPI_SD0), U3.5 (DI(IO0))
/QSPI_SD1: U1.59 (QSPI_SD1), U3.2 (DO(IO1))
/QSPI_SD2: U1.58 (QSPI_SD2), U3.3 (IO2)
/QSPI_SD3: U1.55 (QSPI_SD3), U3.7 (IO3)
/QSPI_SS: R6.1, R10.1, U1.60 (QSPI_SS)
/RUN: J3.29, SW2.2, U1.26 (RUN)
/SWCLK: J3.33, J4.1, U1.24 (SWCLK)
/SWD: J3.31, J4.3, U1.25 (SWD)
/USB_D+: J1.3 (D+), R7.1
/USB_D-: J1.2 (D-), R8.1
/VREG_AVDD: C9.1, R5.2, U1.46 (VREG_AVDD)
/VREG_LX: L1.2, U1.48 (VREG_LX)
/XIN: C3.1, U1.21 (XIN), Y1.1
/XOUT: R2.1, U1.22 (XOUT)
/~USB_BOOT: R6.2, SW1.2
GND: C1.2, C2.2, C3.2, C4.2, C5.2, C6.2, C7.2, C8.2, C9.2, C10.2, C11.2, C12.2, C13.2, C14.2, C15.2, C16.2, C17.2, C18.2, C19.2, J1.5 (GND), J1.6 (Shield), J2.1, J2.3, J2.5, J2.7, J2.9, J2.11, J2.13, J2.15, J2.17, J2.19, J2.21, J2.23, J2.25, J2.27, J2.29, J2.31, J2.33, J2.35, J2.36, J3.2, J3.4, J3.6, J3.8, J3.10, J3.12, J3.14, J3.16, J3.18, J3.20, J3.22, J3.24, J3.26, J3.28, J3.30, J3.32, J3.34, J3.35, J3.36, J4.2, J4.MP (MountPin), R4.2, SW1.1, U1.47 (VREG_PGND), U1.61 (GND), U2.1 (GND), U3.4 (GND), Y1.2, Y1.4
unnamed: C4.1, R2.2, Y1.3
unnamed: R4.1, SW2.1
unnamed: R8.2, U1.51 (USB_DM)
unnamed: R7.2, U1.52 (USB_DP)
VBUS: C1.1, J1.1 (VBUS), U2.3 (VI)

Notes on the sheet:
JST Debug Connector
IOs
Flash
Make sure R7 and R8 are close to RP2350
12MHz Crystal
Power

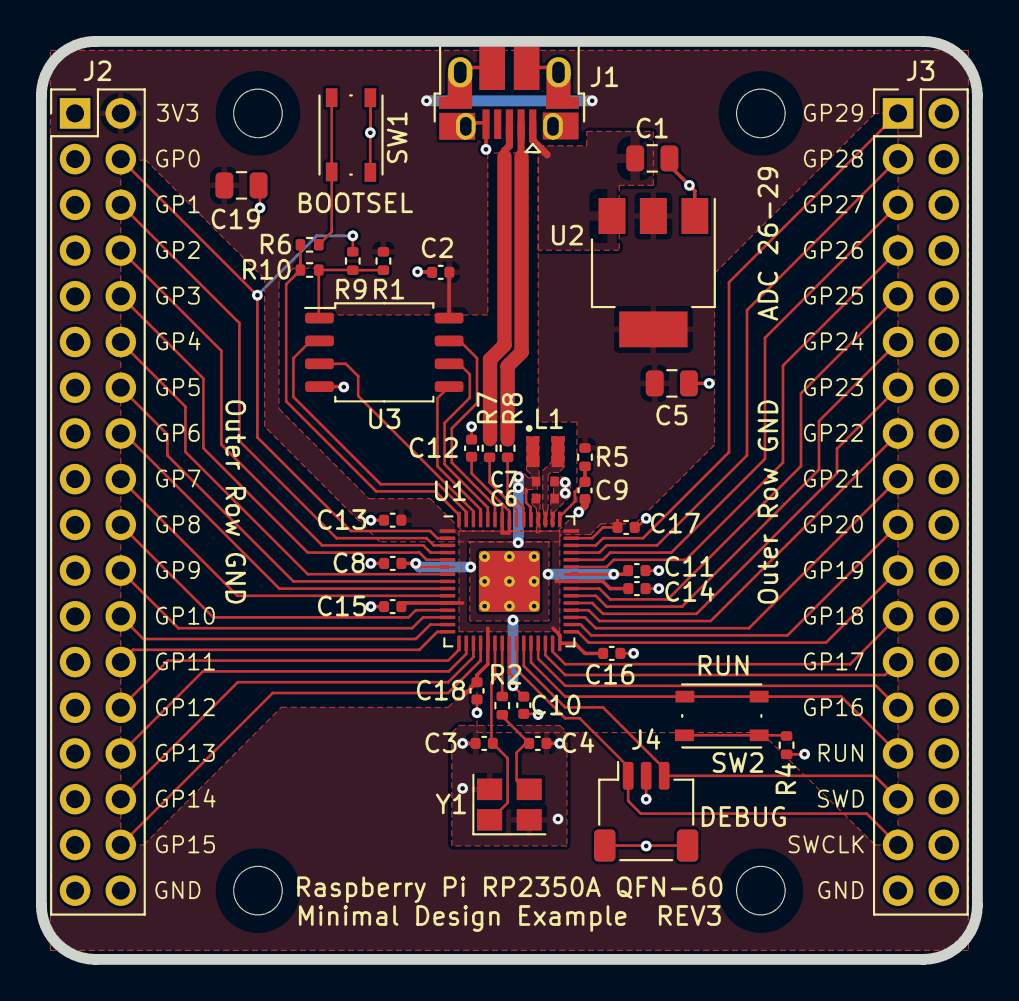
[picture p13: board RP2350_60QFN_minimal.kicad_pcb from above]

Board: 2 copper layers, 52.0 x 51.0 mm, 43 parts (0 on the bottom side), 55 nets.

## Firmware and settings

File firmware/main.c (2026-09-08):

/**
 * Copyright (c) 2020 Raspberry Pi (Trading) Ltd.
 *
 * SPDX-License-Identifier: BSD-3-Clause
 */

#include "pico/stdlib.h"

#ifndef LED_DELAY_MS
#define LED_DELAY_MS 250
#endif

#ifndef PICO_DEFAULT_LED_PIN
#warning blink_simple example requires a board with a regular LED
#endif

// Initialize the GPIO for the LED
void pico_led_init(void) {
#ifdef PICO_DEFAULT_LED_PIN
    // A device like Pico that uses a GPIO for the LED will define PICO_DEFAULT_LED_PIN
    // so we can use normal GPIO functionality to turn the led on and off
    gpio_init(PICO_DEFAULT_LED_PIN);
    gpio_set_dir(PICO_DEFAULT_LED_PIN, GPIO_OUT);
#endif
}

// Turn the LED on or off
void pico_set_led(bool led_on) {
#if defined(PICO_DEFAULT_LED_PIN)
    // Just set the GPIO on or off
    gpio_put(PICO_DEFAULT_LED_PIN, led_on);
#endif
}

int main() {
    pico_led_init();
    while (true) {
        pico_set_led(true);
        sleep_ms(LED_DELAY_MS);
        pico_set_led(false);
        sleep_ms(LED_DELAY_MS);
    }
}

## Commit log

2026-09-08 add initial board design files
    [RP2350_60QFN_minimal.kicad_pcb, RP2350_60QFN_minimal.kicad_sch, RP2350_80QFN_minimal.kicad_pcb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]
2026-09-09 add a decouliping capacitor to flash, a pullup to PMOS power control, and clean schematics
    [chickenboot-jtag-wch.kicad_pcb, chickenboot-jtag-wch.kicad_sch, chickenboot-rpi.kicad_pcb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]
2026-09-09 clean schematics and version match between schematics and PCB
    [chickenboot-rpi.kicad_pcb, chickenboot-rpi.kicad_sch]
2026-09-09 add BOM/POS for manufacturing and related fixes
    [chickenboot-rpi.kicad_pcb, chickenboot-rpi.kicad_sch, chickenboot-rpi_bom.csv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]
2026-09-10 change boards shape and fixes for manufacturability
    [chickenboot-jtag-wch.kicad_pcb, chickenboot-jtag-wch.kicad_sch, chickenboot-jtag-wch_bom.csv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]
2026-09-10 add status led and use all 27R instead of 33R to optimize components
    [chickenboot-rpi.kicad_pcb, chickenboot-rpi.kicad_sch, chickenboot-rpi_bom.csv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]
2026-09-10 fix vias and tracks to pass DFM
    [chickenboot-jtag-wch.kicad_pcb, chickenboot-rpi.kicad_pcb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]

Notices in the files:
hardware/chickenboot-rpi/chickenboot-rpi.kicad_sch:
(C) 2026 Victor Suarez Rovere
